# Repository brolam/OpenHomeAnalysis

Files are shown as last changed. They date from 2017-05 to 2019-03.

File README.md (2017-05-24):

# OHA - Open Home Analysis
<p>
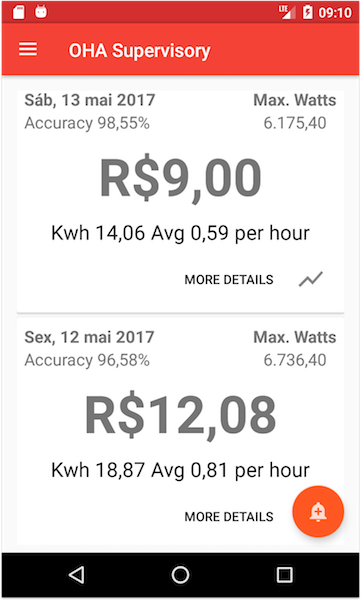
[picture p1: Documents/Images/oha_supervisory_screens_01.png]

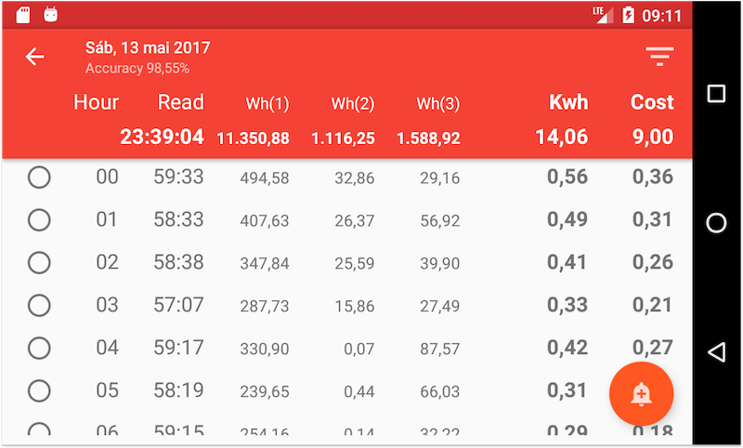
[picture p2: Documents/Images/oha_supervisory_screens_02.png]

</p>
OHA é uma solução desenvolvida sobre as plataformas Arduino e Android para analisar informações registradas por sensores instalados em uma residência. 

O primeiro sensor disponível registra a utilização de energia de todos os aparelhos conectados a rede elétrica da residência e todas as informações são analisadas através do aplicativo Supervisory para Android, que será responsável pelo armazenamento e disponibilização dessas informações.

É importante destacar que cada aparelho gera uma assinatura na utilização de energia na rede elétrica, dessa forma, é possível analisar a utilização de energia por aparelho e período através do aplicativo Supervisory.

Esse é um projeto Open Source / Open Hardware, sendo assim, todas as informações necessárias para desenvolve-lo estão disponíveis nesse repositório, além disso, também recomendo os vídeos abaixo disponíveis no youtube com mais detalhes do projeto: 

- [Visão Geral do Projeto](https://youtu.be/oC_cOZK9y08);
- [Desenvolvendo o Registrador de Utilização de Energia](https://youtu.be/WqODX3P4kZ0);

## Registrador de Utilização de Energia

### Protoboard
<p align="center">
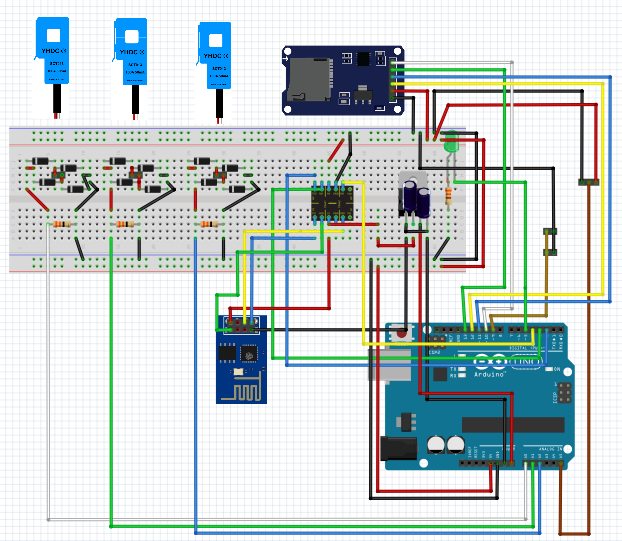
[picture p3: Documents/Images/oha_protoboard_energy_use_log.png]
  
</p> 

### PCB
<p align="center">
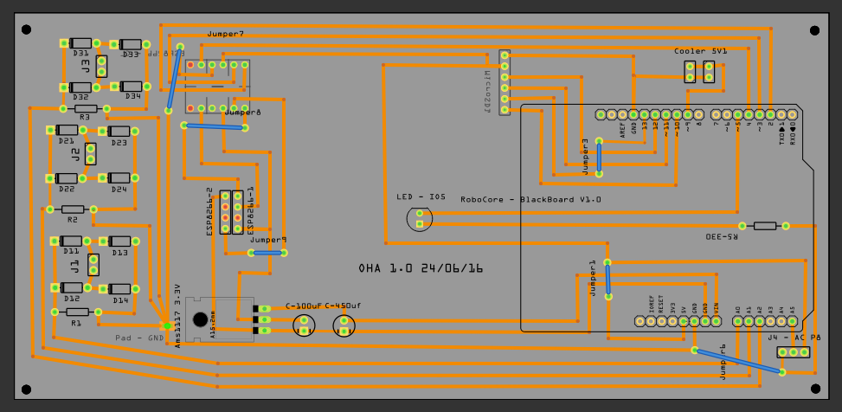
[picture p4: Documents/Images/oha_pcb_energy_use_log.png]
  
</p>
O objetivo da Protoboard na imagem acima é fornecer uma visão geral dos componentes e suas conexões, mas sugiro a construção da PCB, conforme orientações abaixo, para evitar problemas com as conexões que podem inviabilizar o funcionamento correto desse circuito. 

Segue abaixo a lista de componentes com o link das lojas onde eles foram adquiridos:
<table>
  <tr>
    <th width="30%">Componentes</th>
    <th>Descrição</th> 
    <th>Objetivo</th>
    <th>Preço</th>
  </tr>
  <tr></tr>
  <tr>
    <th></th>
    <th>Arduino UNO R3 ou compatível fabricado pela RoboCore.</th> 
    <th>Ler através das portas analógicas a utilização de energia e registrar no SD Card.</th>
    <th><a href="https://www.robocore.net/loja/produtos/arduino-blackboard.html">R$85,00</a></th>
  </tr>
  <tr></tr>
  <tr>
    <th></th>
    <th>MicroSD Card Adapter CATALEX v1.0.</th> 
    <th>Registrar temporariamente a utilização de energia.</th>
    <th><a href="http://www.usinainfo.com.br/modulos-para-arduino/sd-card-arduino-leitor-micro-sd-card-2637.html">R$12,90</a></th>
  </tr>
  <tr></tr>
  <tr>
    <th></th>
    <th>Módulo ESP8266-01</th> 
    <th>Disponibilizar os registros de utilização de energia através de uma conexão WiFI.</th>
    <th><a href="https://www.robocore.net/loja/produtos/modulo-wifi-esp8266.html">R$39,00</a></th>
  </tr>
  <tr></tr>
  <tr>
    <th></th>
    <th>Conversor de Nível Lógico RC 3,3V / 5V</th> 
    <th>Converter o nível lógico de 5V do Arduino para 3,3V na comunicação serial com o Módulo ESP8266-01.</th>
    <th><a href="https://www.robocore.net/loja/produtos/conversor-de-nivel-logico.html">R$8,50</a></th>
  </tr>
  <tr></tr>
  <tr>
    <th></th>
    <th>Regulador de Tensão Ams1117 3.3v P/ Esp8266</th> 
    <th>Transformar a alimentação do circuito de 9V para 3.3V e alimentar o Módulo ESP8266-01</th>
    <th><a href="http://produto.mercadolivre.com.br/MLB-711669968-modulo-regulador-tensao-ams1117-33v-p-esp8266-wifi-arduino-_JM">R$5,00</a></th>
  </tr>
  <tr></tr>
  <tr>
    <th></th>
    <th>3 X Sensores de Corrente Não Invasivo 100A SCT-013</th> 
    <th>Realizar a leitura da utilização de energia</th>
    <th><a href="http://www.filipeflop.com/pd-2025cd-sensor-de-corrente-nao-invasivo-100a-sct-013.html?ct=&p=1&s=1">R$47.90X3 = R$143,70</a></th>
  </tr>
  <tr></tr>
  <tr>
    <th></th>
    <th>Capacitor Eletrolítico 470uF / 16V</th> 
    <th>Estabilizar a alimentação entre a fonte de 9V e o regulador Tensão Ams1117 3.3v</th>
    <th><a href="http://www.baudaeletronica.com.br/capacitor-eletrolitico-470uf-16v.html">R$0,20</a></th>
  </tr>
  <tr></tr>
  <tr>
    <th></th>
    <th>Capacitor Eletrolítico 10uF / 16V</th> 
    <th>Estabilizar a alimentação entre o regulador de Tensão Ams1117 3.3v e o Módulo ESP8266-01</th>
    <th><a href="http://www.baudaeletronica.com.br/capacitor-eletrolitico-10uf-16v.html?gclid=CJGrgOLo7NMCFUlMDQodi3kNyw">R$0,20</a></th>
  </tr>
  <tr></tr>
  <tr>
    <th></th>
    <th>3 X Resistores (33Ω)</th> 
    <th>Dividir a tensão do SCT-013 para os 5V nas portas analógicas do Arduino</th>
    <th><a href="http://www.baudaeletronica.com.br/resistor-33r-5-1-4w.html">R$0.10X3 = R$0,30</a></th>
  </tr>
  <tr></tr>
  <tr>
    <th></th>
    <th>12 X Diodos In4007 ou equivalentes</th> 
    <th>Transformar a corrente alternada do SCT-013 em corrente contínua através de uma ponte retificadora.</th>
    <th>R$0.20X12 = R$2,40</th>
  </tr>
  <tr></tr>
  <tr>
    <th></th>
    <th>3 X Conectores 5045 2 Pinos Macho</th> 
    <th>Conectar os SCT-013 ao circuito.</th>
    <th><a href="http://www.usinainfo.com.br/conectores-e-soquetes/conector-5045-2-pinos-macho-kit-com-5-unidades-3485.html">R$0,32X3 = R$0,96</a></th>
  </tr>
  <tr></tr>
  <tr>
    <th></th>
    <th>3 X Conectores 5051 2 Pinos Fêmea</th> 
    <th>Conectar os SCT-013 ao circuito.</th>
    <th><a href="http://www.usinainfo.com.br/conectores-e-soquetes/conector-5045-2-pinos-macho-kit-com-5-unidades-3485.html">R$0,38X3 = R$1,14</a></th>
  </tr>
  <tr></tr>
  <tr>
    <th></th>
    <th>2 X Barras de 10 pinos fêmea / Conector Empilhável</th> 
    <th>Conectar o MicroSD Card e Regulador Tensão Ams1117 ao circuito.</th>
    <th><a href="http://www.usinainfo.com.br/barras-de-pinos/barra-de-10-pinos-femea-conector-empilhavel-2530.html">R$2,00X2 = R$4,00</a></th>
  </tr>
  <tr></tr>
  <tr>
    <th></th>
    <th>Barra de 40 pinos fêmea / Conector Empilhável para PCI</th> 
    <th>Conectar o Módulo ESP8266-01 e Conversor de Nível Lógico RC 3,3V ao circuito.</th>
    <th>
        <a href="http://www.usinainfo.com.br/barras-de-pinos/barra-de-40-pinos-femea-conector-empilhavel-para-pci-3109.html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">R$3,85</a>
    </th>
  </tr>
  <tr></tr>
  <tr>
    <th></th>
    <th>Barra de pinos macho 1x40 vias com passo de 2,54mm 180°</th> 
    <th>Conectar o Arduino UNO R3 ou compatível ao circuito.</th>
    <th>
        <a href="http://www.usinainfo.com.br/barras-de-pinos/barra-de-pinos-macho-1x40-vias-com-passo-de-254mm-180-preto-2748.html">R$1,90</a>
    </th>
  </tr>
  <tr></tr>
  <tr>
    <th></th>
    <th>Placa de Fenolite Cobreada Simples 10x20 cm</th> 
    <th></th>
    <th>
         <a href="http://www.usinainfo.com.br/circuito-impresso/placa-de-fenolite-cobreada-simples-10x20-cm-para-circuito-impresso-3841.html">R$6,90</a>
    </th>
  </tr>
  <tr></tr>
  <tr>
    <th></th>
    <th>LED 5mm Difuso e um Resistor de (330Ω) </th> 
    <th>Informar se a utilização de energia foi registrada com sucesso.</th>
    <th>
         <a href="http://www.usinainfo.com.br/leds/led-amarelo-5mm-difuso-kit-com-5-unidades-2978.html">R$0,40 + R$0,30 = R$0,70</a>
    </th>
  </tr>
  <tr></tr>
  <tr>
    <th></th>
    <th>Fonte de Alimentação para Arduino 9VDC 1A</th> 
    <th>Alimentar todo o circuito.</th>
    <th><a href="http://www.usinainfo.com.br/fonte-de-alimentacao/fonte-de-alimentacao-para-arduino-9vdc-1a-2424.html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">R$18,85</a>
    </th>
  </tr>
  <tr></tr>
  <tr>
    <th></th>
    <th>Cartão De Memória Microsd 2gb</th> 
    <th>Armazenar temporariamente os registros de utilização de energia.</th>
    <th>R$15,85</th>
  </tr>
</table>
O custo estimado considerando somente os componentes é de aproximadamente R$351,35, sendo importante destacar que será necessário dedicar um smartphone ou tablet Android para monitorar o Registrador de Energia.

## Construindo e Instalando o Registrador de Utilização de Energia
### PCB

<p align="center">
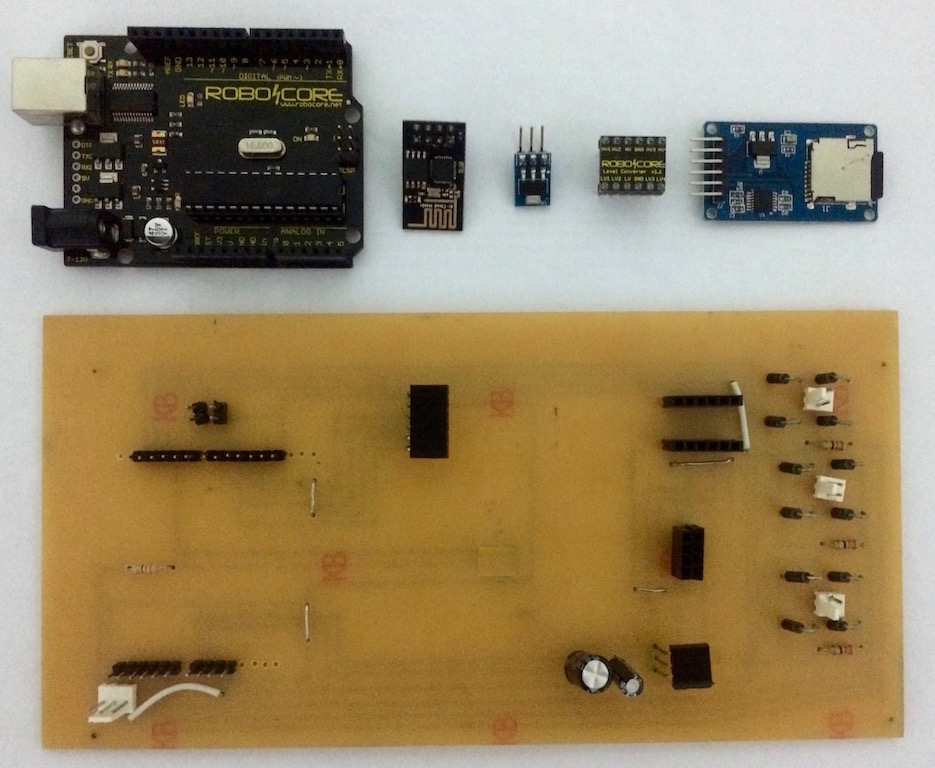
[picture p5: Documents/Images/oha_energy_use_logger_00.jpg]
  
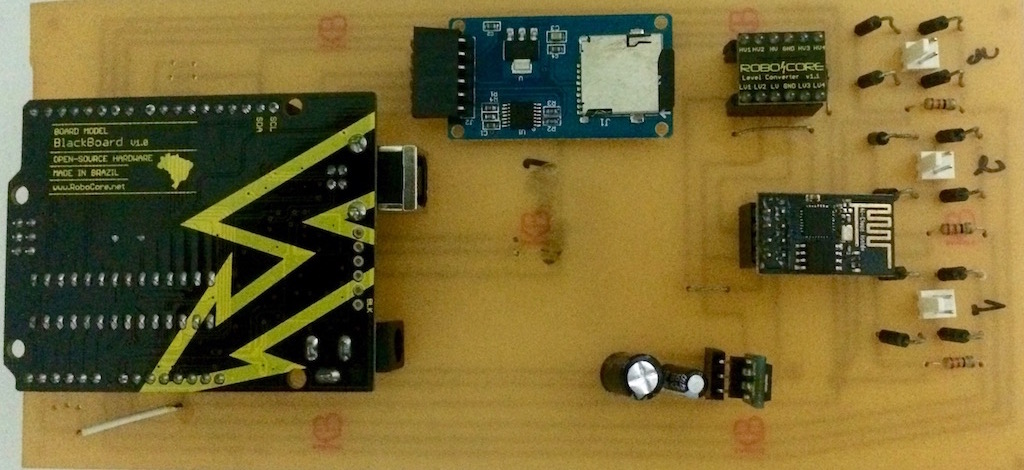
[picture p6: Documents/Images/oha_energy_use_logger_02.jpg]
  
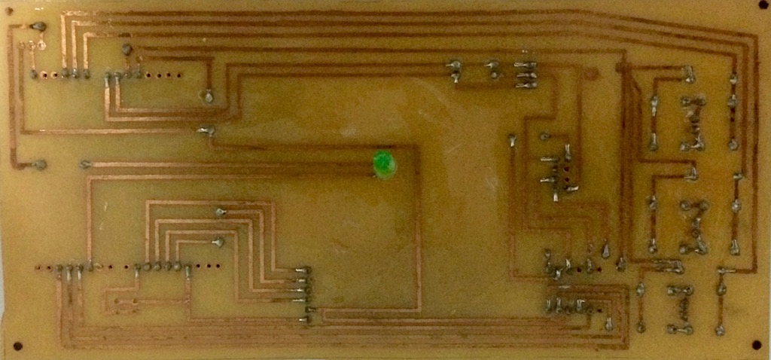
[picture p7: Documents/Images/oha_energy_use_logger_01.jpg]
  
</p>
A placa pode ser construída utilizando a técnica de termotransferência do circuito impresso via impressora laser, sendo assim, o <a href="https://raw.githubusercontent.com/brolam/OpenHomeAnalysis/master/Documents/Images/oha_pcb_energy_use_logger.pdf">PDF</a> do circuito também está disponível nesse repositório para facilitar a impressão. <br>Também clique na imagem acima para ampliá-la é visualizar com mais detalhes como cada componente deve ser instalado na placa.

### Instalação 
<table>
  <tr>
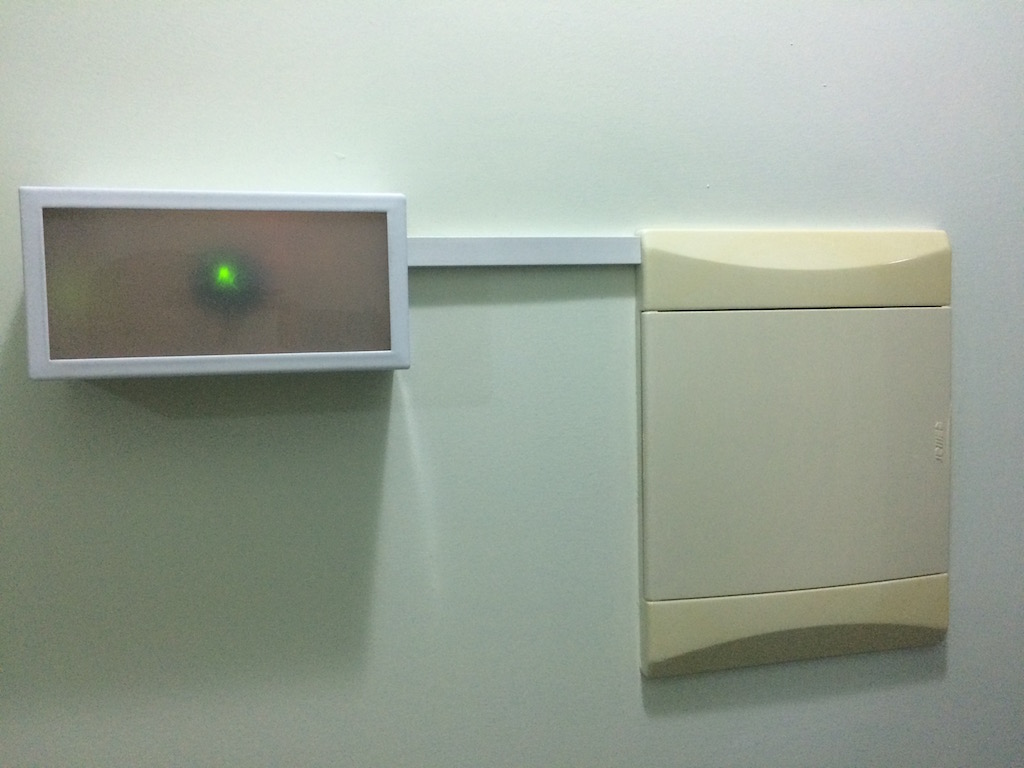
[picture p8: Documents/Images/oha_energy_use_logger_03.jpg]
    <th th width="40%"></th>
    <th>A placa junto com a fonte de 9V podem ser instaladas em uma ARANDELA medindo 20cmX10cm e 7,5cm de profundidade ao lado do quadro de distribuição elétrica;</th>
  </tr>
  <tr></tr>
  <tr>
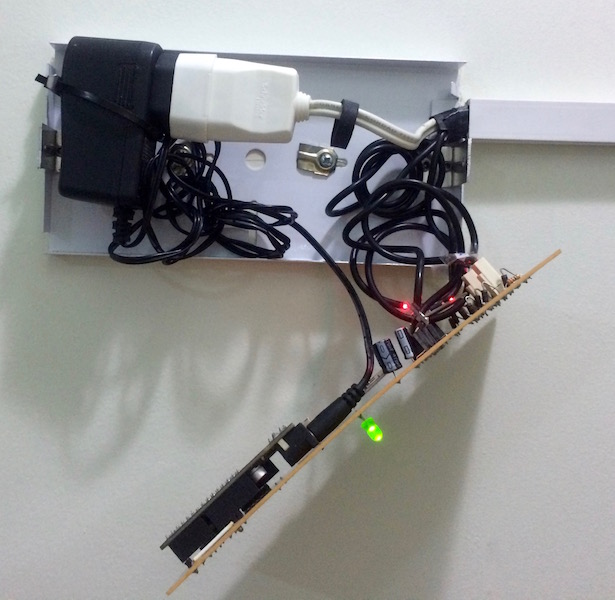
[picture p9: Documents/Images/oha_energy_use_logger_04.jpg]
    <th></th>
    <th>Veja na imagem ao lado a instalação da placa junto com a fonte de 9V;</th> 
  </tr>
  <tr></tr>
  <tr>
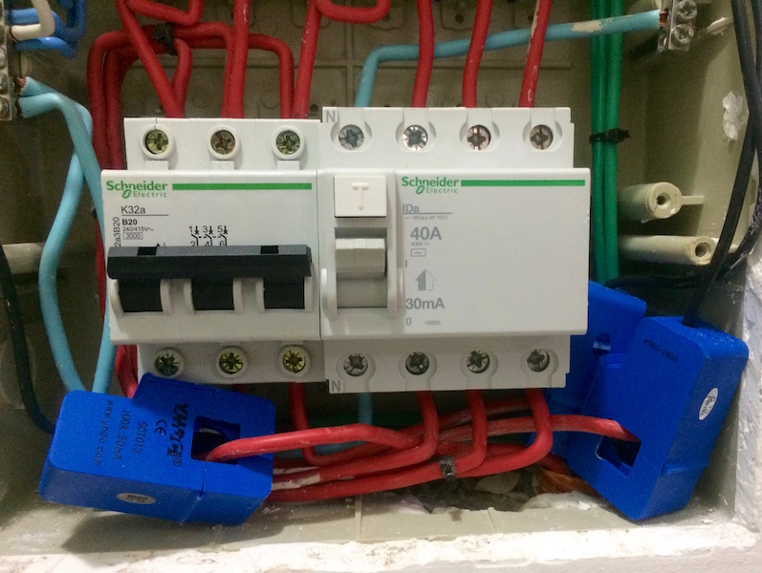
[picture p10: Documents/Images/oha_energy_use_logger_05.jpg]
    <th></th>
    <th>Também observe a instalação dos sensores SCT-013 em cada fase.</th> 
  </tr>
</table>

## Carregando o Firmware no Módulo ESP8266 e Arduino 

### ESP8266
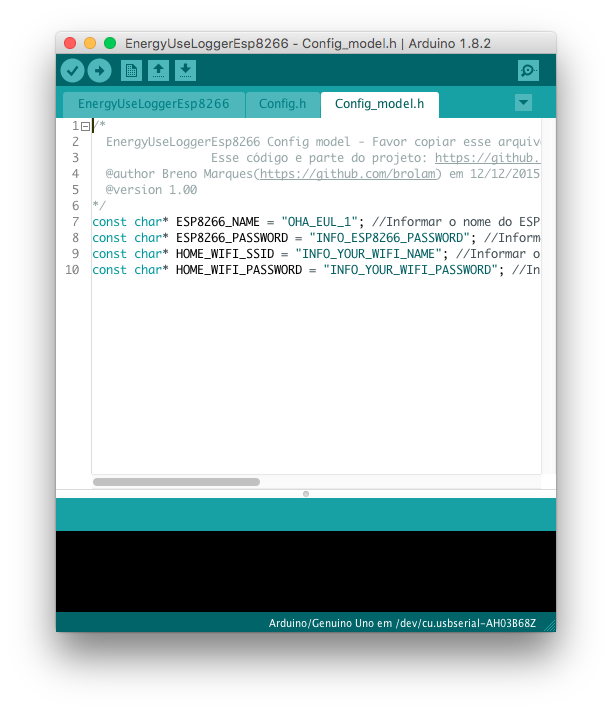
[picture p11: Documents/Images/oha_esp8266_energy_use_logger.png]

Antes de carregar o firmware disponível em <a href="https://github.com/brolam/OpenHomeAnalysis/tree/master/Firmware/EnergyUseLoggerEsp8266">Firmware/EnergyUseLoggerEsp8266</a> no módulo ESP8266, é necessário copiar o arquivo Config_model.h para o Config.h no mesmo diretório e configurar os parâmetros exibidos na imagem acima. Caso exista alguma dificuldade para conectar o módulo ESP8266 via USP e realizar a carga, sugiro a leitura do tutorial disponível em <a href="https://www.robocore.net/loja/produtos/modulo-wifi-esp8266.html">www.robocore.net</a>.

### Arduino
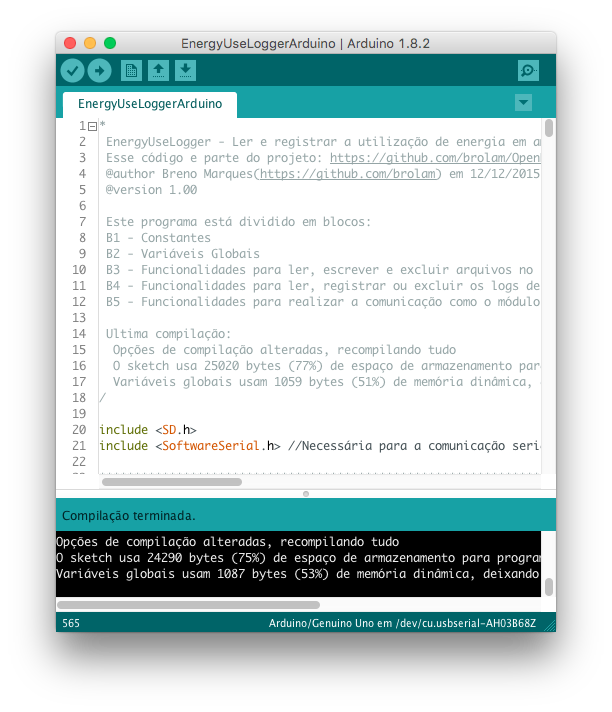
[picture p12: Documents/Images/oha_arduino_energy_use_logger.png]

O firmware para o Arduino está disponível em <a href="https://github.com/brolam/OpenHomeAnalysis/tree/master/Firmware/EnergyUseLoggerArduino">Firmware/EnergyUseLoggerArduino</a>. </br>Observação: se o Arduino estiver conectado a placa, também será necessário conectá-lo a fonte de 9V, porque somente a alimentação via USB não será suficiente para alimentar todo o circuito.

### Fritzing
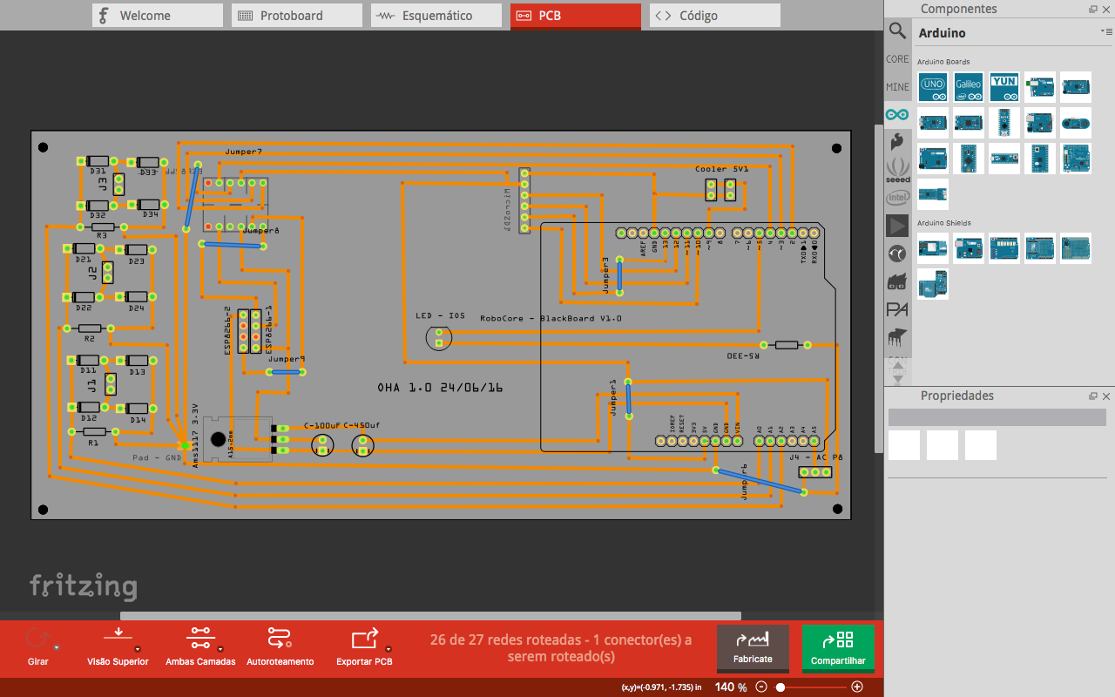
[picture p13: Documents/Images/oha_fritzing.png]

Caso seja necessário realizar alguma modificação no circuito, o arquivo .fzz também está disponível nesse repositório <a href="https://github.com/brolam/OpenHomeAnalysis/tree/master/Documents/Fritzing/OhaEnergyUseLog.fzz">Documents/Fritzing/</a>.

## Instalando e Configurando o Aplicativo Supervisory

### Instalação através do Google Play
O aplicativo Supervisory está disponível na loja de aplicativos, favor procurar por <a href="https://play.google.com/store/apps/details?id=br.com.brolam.oha.supervisory">OHA - Open Home Analysis</a> e realizar a instalação.

### Instalação através do Android Studio
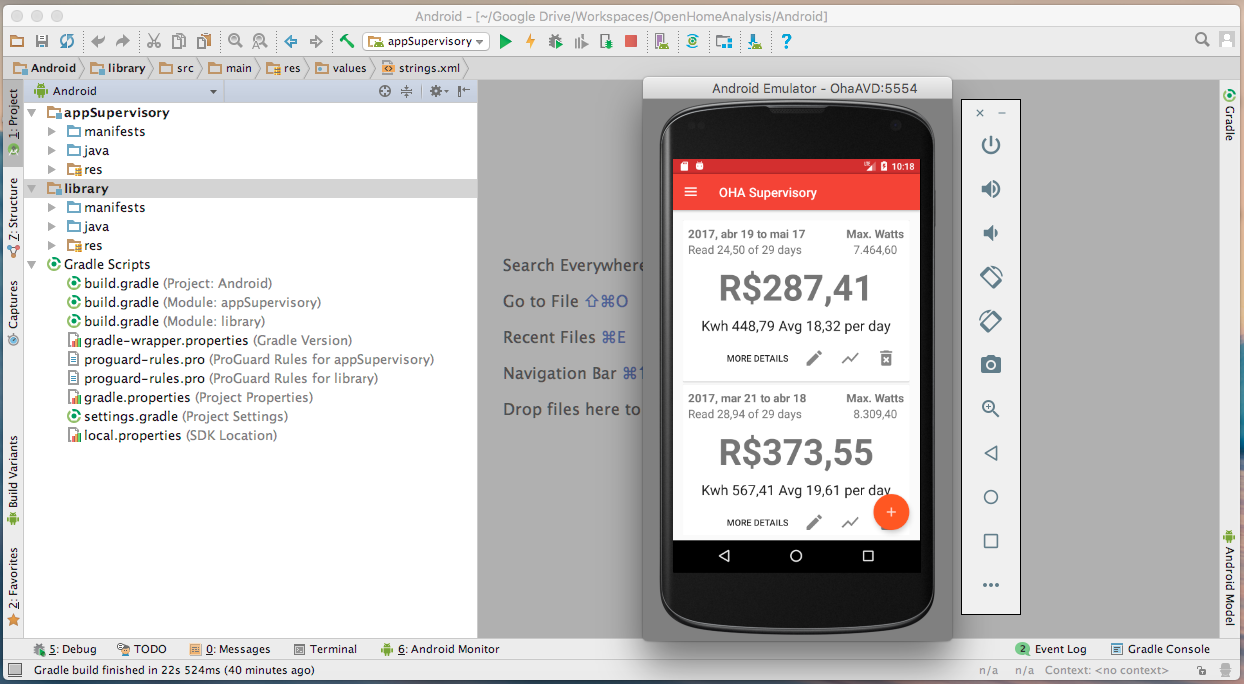
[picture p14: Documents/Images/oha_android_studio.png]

O código fonte do aplicativo Supervisory também está disponível nesse repositório em <a href="https://github.com/brolam/OpenHomeAnalysis/tree/master/Android">Android/</a>. Sendo assim, é possível realizar a instalação e modificações através do Android Studio.

### Configurando o Registrador de Utilização de Energia no aplicativo Supervisory
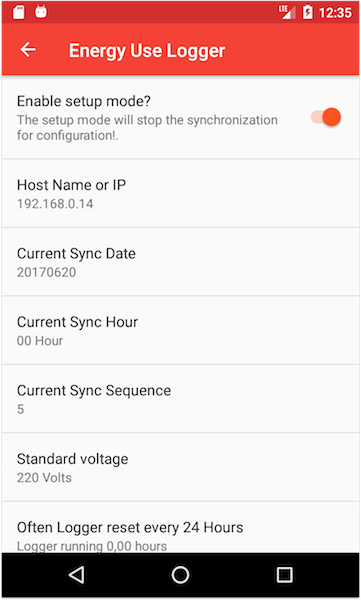
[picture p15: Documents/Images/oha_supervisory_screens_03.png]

No aplicativo /Settings/Energy Use Logger, conforme imagem acima, é possível preencher os parâmetros para conectar o aplicativo ao Registrador de Utilização de Energia.

## Próximas Funcionalidades
Novas funcionalidades, melhorias e correções serão cadastradas na <a href="https://github.com/brolam/OpenHomeAnalysis/issues">Lista de Questões(Issues)</a> desse repositório, então, basta seguir esse repositório para receber notificacões sobre as novidades.

## Contribuições
Fique a vontade para contribuir e acompanhe a <a href="https://github.com/brolam/OpenHomeAnalysis/issues">Lista de Questões(Issues)</a> do projeto ou entre em contato através do e-mail breno@brolam.com.br

## Links importantes para o desenvolvimento do projeto

- <a href="https://www.embarcados.com.br/">Embarcados</a> 
- <a href="https://openenergymonitor.org/">Open Energy Monitor</a> 
- <a href="https://www.youtube.com/channel/UCpOlOeQjj7EsVnDh3zuCgsA">Eletrônica Já!</a> 
- <a href="https://www.youtube.com/channel/UClT57Bq5io_kABtihe67C7w">All Electronics</a> 
- <a href="http://www.usinainfo.com.br/">Usinainfo</a> 
- <a href="https://www.robocore.net/">Robocore</a> 
- <a href="https://www.youtube.com/channel/UCpOlOeQjj7EsVnDh3zuCgsA">Adafruit Industries</a> 
- <a href="https://www.youtube.com/channel/UCVHFbqXqoYvEWM1Ddxl0QDgw">Android Developers</a>

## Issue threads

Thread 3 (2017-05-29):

App Supervisory - Tela de detalhes da conta de energia.

brolam, 2017-05-29:
Desenvolver a tela de detalhes da conta de energia:
1 - Exibir a utilização de energia por dia no período da conta de energia;
2 - Permitir a realização de filtros por faixa de hora, minuto e segundo e também por faixa de watts por fase.

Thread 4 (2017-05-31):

GO V1.0 - Processo de autenticação do Usuário.

brolam, 2017-05-31:
- Criar projeto no Firebase e configurar o authentication providers.
- Criar processo de autenticação no aplicativo Supervisory.
- Criar processo de autenticação no aplicativo OHA GO iOS.

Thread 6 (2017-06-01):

Energy Use Logger V2.0 - S1

brolam, 2017-06-01:
Desenvolver o registrador de utilização de energia através da seguinte solução:
S1 - NodeMcu Lua CH340G ESP8266 com Leonardo Pro Micro ATmega32U4

brolam, 2017-06-17:
Realizado teste de gravação e leitura no Micro SD Card: Não foi possível realizar a conexão alimentando o módulo com 3.3V, mas a gravação e leitura foi realizada com sucesso e com uma ótima performance alimentando o módulo Micro SD Card com 5V.

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

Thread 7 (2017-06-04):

EnergyUseLogger - Arduino Travamento

brolam, 2017-06-04:
Depois de horas ou dias somente o Arduino trava interrompendo o registro de utilização de energia, mas o módulo ESP8266 continua respondendo as requisições http.

brolam, 2017-06-04:
Foi identificado que o travamento acontece na leitura ou escrita no MicroSD, e somente após uma formatação completa do MicroSD o problema foi corrigido. Novos testes serão realizados para confirmar a correção do problema.

Closed 2017-06-09.

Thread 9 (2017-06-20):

Melhorar o caso de teste OhaEnergyUseApiV1Test.

brolam, 2017-06-20:
Melhorar o caso de teste com o objetivo de testar o comportamento da OhaEnergyUseApiV1 independente do modelo do OhaEnergyUseLogger que ela está conectada.

Assim será possível verificar que todos os modelos do OhaEnergyUseLogger ( Arduino ou NodeMcu ) estão realizando o mesmo comportamento no registro e leitura da utilização de energia.

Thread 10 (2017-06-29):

EnergyUseLogger - Lentidão na gravação dos registros de utilização de energia.

brolam, 2017-06-29:
Depois de armazenar mais de cincos dias no Micro-SD de 8G, está ocorrendo uma lentidão na gravação nos logos de utilização de energia.

Esse problema também está diminuindo a precisão no tempo total de leitura da utilização de energia.

Closed 2017-07-01.

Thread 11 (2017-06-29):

EnergyUseLogger - Erro na exclusão dos registros temporários de utilização de energia.

brolam, 2017-06-29:
Para liberar espaço no Micro-SD, o registrador de utilização de energia deve excluir os registros que já foram exportado para o aplicativo Supervisory. Mas esse processo está travando o registrador no momento da exclusão do registro de utilização de energia.

brolam, 2017-07-17:
Esse problema será corrigido na nova versão do registrador: issue #6

Closed 2017-07-17.

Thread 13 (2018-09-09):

Gravar registros de energia

brolam, 2018-09-09:
Refazer a funcionalidade de gravação e importação dos registros de energia para melhoria a performance, diminuir o tamanho do programa e corrigir a exclusão dos registros já importados.

brolam, 2018-11-02:
Concluído. Aplicativo também atualizado e disponível em https://play.google.com/store/apps/details?id=br.com.brolam.oha.supervisory

Closed 2018-11-02.

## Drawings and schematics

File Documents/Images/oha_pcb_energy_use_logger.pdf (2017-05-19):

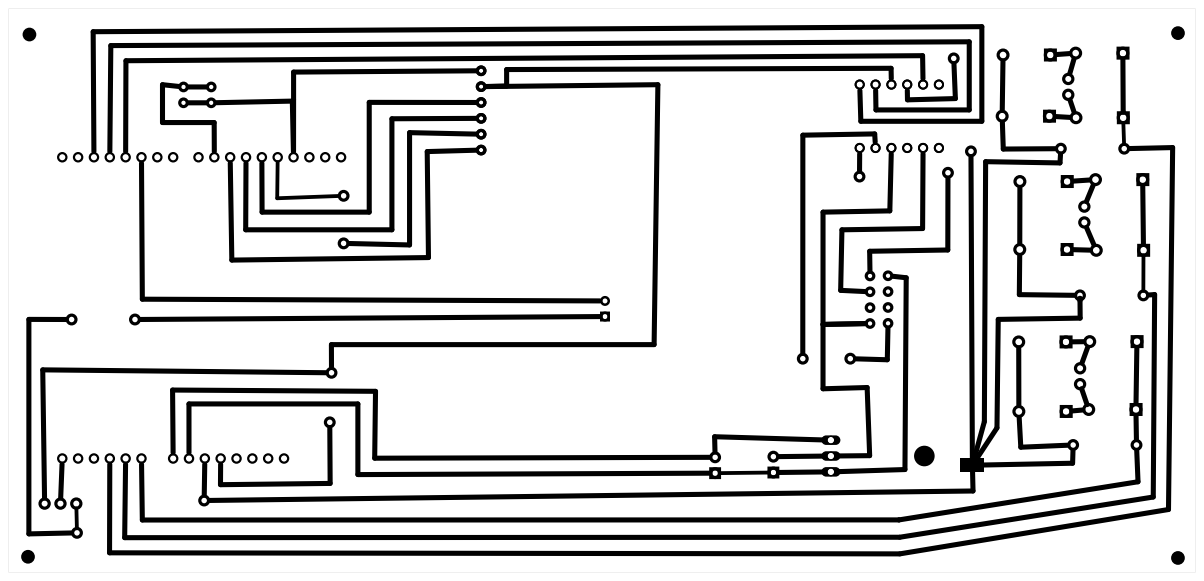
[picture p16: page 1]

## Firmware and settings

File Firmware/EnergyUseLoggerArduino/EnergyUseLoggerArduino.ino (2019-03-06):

/*
  EnergyUseLogger - Ler e registrar a utilização de energia lendo os sensores SCT - 013 conectados ao circuito.
  Esse código e parte do projeto: https://github.com/brolam/OpenHomeAnalysis
  @author Breno Marques(https://github.com/brolam) em 12/12/2015.
  @version 1.2.0
*/

#include <SD.h>
#include <SoftwareSerial.h> //Necessária para a comunicação serial com o modulo WiFi ESP8266.
//#define DEBUG 1 //Escrever no Monitor serial quando ativado, {@see debug()},
#define LED_LOG_SAVE 5                  //Informar a porta do LED, para sinalizar a gravação do log da utilização de energia. 

//Constantes utilizadas na geração dos logs.
#define AMOUNT_SCT 3                    //Quantidade de sensores SCT-013 suportado no circuito.  
#define INTERVAL_TIME_SAVE_LOG 10000    //Intervalo em Milissegundo para registrar o proximo log, {@see saveLog()}    

//Constantes utilizadas na gravação dos arquivos.
#define SD_CS 10                        //The pin connected to the chip select line of the SD card, @link https://www.arduino.cc/en/Reference/SDbegin
#define F_BEGIN F("<")                  //Sinalizar o inicio do conteúdo de registro de utilização de entergia 
#define F_END F(">")                    //Sinalizar o final do conteúdo de registro de utilização de entergia
#define LINE_END '\n'                   //Sinalizar o final da linha do registro de utilização de entergia
#define F_TXT F(".txt")                 //Extensão dos arquivos de logs de registros de energia

//Constantes utilizadas na comunicação com o modulo WiFi ESP8266
#define URL_LOG F("log")                                 //Solicitação de logs
#define URL_STATUS F("status")                           //Solicitação(GET) ou alteração(POST) do Status do programa, para mais detalhes {@see setStatus()} e {@see sendStatus()} 
#define URL_RESET F("reset")                             //Solicitação para reiniciar o Arduino, para mais detalhes {@see reset()}
#define LOG_DATE_NOT_EXISTS F("LOG_DATE_NOT_EXISTS")     //Sinalizar que o log não existe na data e hora solicitada.
#define LOG_END_OF_FILE F("LOG_END_OF_FILE")             //Sinalizar que a leitura dos logs chegou ao final.
#define LOG_DELETED F("LOG_DELETED")                     //Sinalizar que o log foi excluido.
#define OHA_STATUS_FINISHED F("OHA_STATUS_FINISHED")     // Sinalizar que a geração de logs está finalizada para a data e hora solicitada
#define OHA_STATUS_RUNNING F("OHA_STATUS_RUNNING")       // Sinalizar que a geração de logs esta ativa  para a data e hora solicitada

//Constantes para definir o status de execução do programa.
#define OHA_STATUS_NOT_DATE F("OHA_STATUS_NOT_DATE")    //Sinalizar que a data do programa não está atualizada. 
#define OHA_STATUS_NOT_SD F("OHA_STATUS_NOT_SD")        //Sinalizar que o SD Card está com problema e os registros dos logs está parado.   
#define OHA_STATUS_OK F("OHA_STATUS_OK")                //Sinalizar que a data do programa está atualizada / registrando os logs de utilização de energia. 

String ohaStatus = String("");                         //Armazenar o status atual do programa.
String currentDate = String("");                       //Armazenar a data atual para o registro dos logs no formato YYYYMMDD
String currentTime = String("");                       //Armazenar a hora + minutos atual para o registro dos logs no forma HHmm
unsigned long millisOnSetTime = 0;                     //Armazenar o total de Milissegundo {@see millis()}, quando a data e hora do programa foi atualizada, para mais detalhes veja {@see setDate()}
unsigned long intervalSaveLog = 0;                     //Armazenar o tempo que o ultimo log foi salvo, por favor, veja {@see saveLog()} para mais detalhes.
byte espCheck = 0;                                     //Armazenar o total de verificação do status do modulo ESP8266 {@see esp8266Reset()}.

SoftwareSerial esp8266(2, 3); //Comunicação serial com o modulo ESP8266.

#ifdef DEBUG
void debug(String title, String value) {
  Serial.print(title); Serial.println(value);
}
#endif

#ifdef DEBUG
void debug(String title) {
  Serial.println(title);
}
#endif

/* Abrir um arquivo no cartão de memória conforme parametros abaixo:
   IMPORTANTE: O arquivo deve ser fechado, {@see file.close()}, no final do processo!
*/
File getFile(String fileName, boolean readOnly) {
  return SD.open(fileName, ( readOnly ? FILE_READ : FILE_WRITE));
}

String getLogFileName(String date, String strTime) {
  return date.substring(0, 6) + strTime.substring(0, 2) + String(F_TXT);
}

String getStatusByDateHour(String strDate, String strHour) {
  return ((strDate == currentDate) && (currentTime.substring(0, 2) == strHour.substring(0, 2)) ? String(OHA_STATUS_RUNNING) : String(OHA_STATUS_FINISHED));
}

/* Preencher uma lista com a média da leituras dos sensores SCT 13 */
void fillReads(double reads[AMOUNT_SCT])
{
  int counts[AMOUNT_SCT];
  double readSum[AMOUNT_SCT];
  //Inicializa os valores das listas com zero:
  for (byte z = 0; z < AMOUNT_SCT; z++) {
    counts[z] = 0;
    readSum[z] = 0.00;
  }
  //Realizar 2000 leituras nas portas analogicas. Essa quantidade de leitura gera um valor mais próximos dos valores
  //medidos com o amperímetro. Somente ler valores maior do que zero.
  for (int i = 0; i < 2000; i++)
  {
    for (int r = 0; r < AMOUNT_SCT; r++)
    {
      int _analogRead = analogRead(r);
      if (_analogRead > 0 )
      {
        readSum[r] += _analogRead;
        counts[r] ++;
      }
    }
  }

  //Aplicar a média das leitura nos sensores:
  for (byte a = 0; a < AMOUNT_SCT; a++)
  {
    reads[a] =  (( counts[a]  > 10 ) ?  (readSum[a] / counts[a]) : 0.00) ;
#ifdef DEBUG
    debug("A" + String(a) + ": " , String((counts[a] > 0 ? ( readSum[a] / counts[a] ) : 0.00)) );
    debug("C" + String(a) + ": " , String(counts[a]) );
#endif
  }
}

/* Registrar um log de utilização de energía no cartão de memória.*/
void saveLog() {
  double reads[AMOUNT_SCT];
  fillReads(reads);

  //Verifica se o tempo de intervalo para gravar o próximo log foi alcançado:
  while ( (millis() - intervalSaveLog) < INTERVAL_TIME_SAVE_LOG ) {
    delay(100);
  }
  //Reiniciar o intervalo do tempo que o log deve ser gavado nesse ponto, para não contabilizar o tempo
  //da gravação do próximo logo.
  intervalSaveLog = millis();
#ifdef DEBUG
  debug(F("Sensors Reads: "), (String(reads[0]) + String(" / ") + String(reads[1]) + String(" / ") + String(reads[2])));
#endif
  String fileName = getLogFileName(currentDate, currentTime); // Nome do arquivo do log.
  File fileLog = getFile(fileName, false);
  fileLog.print(F_BEGIN); // Inicio do conteúdo do log
  fileLog.print(currentTime.substring(0, 6)); fileLog.print('|'); //Ultima hora e minuto atualizada no programa.
  fileLog.print(getVolts()); fileLog.print('|');
  //Gerar um coluna para cada leitura dos SCT 013 disponíveis no circuito:
  for (byte s = 0; s < AMOUNT_SCT; s++)
  {
    fileLog.print((reads[s] > 0 ? reads[s] : 0.00)); fileLog.print('|');
  }
  fileLog.print(millis() - millisOnSetTime); //Total de Milissegundo desde a ultima atualização da data e hora no programa, para mais detalhes, veja B4/Observação 02.
  fileLog.print(F_END); //Final do conteudo do log, somente logs com essa sinalização serão considerados válidos.
  fileLog.print(LINE_END); //Sinaliza o final do log ou final da linha no arquivo de log.
  fileLog.close();
#ifdef DEBUG
  debug(F("path:"), fileName);
#endif
}

/* Enviar uma lista de logs para o módulo ESP8266 via comunicação serial conforme parametros abaixo:
   @param strDate informar texto com data no formato YYMMDD
   @param strHour informar texto com hora e minuto no formato HHmm
   @param start informar o inicio da sequência do log.
   @param amount informar a quantidade de logs.
*/
void sendLog(String strDate, String strHour, int startPosition, int amount ) {
  int countReadLogs = 0;
  String pathLog = getLogFileName(strDate, strHour);
  if ( !SD.exists(pathLog) ) {
    esp8266.println(LOG_DATE_NOT_EXISTS);
    return;
  }
  File logFile = getFile(pathLog, true);
  if ( !logFile.seek(startPosition)  )
  {
    esp8266.println(String(LOG_END_OF_FILE));
#ifdef DEBUG
    debug(F("SendLog not seek: "), String(startPosition));
#endif
    return;
  }
  do {
    String nextLogContent = logFile.readStringUntil(LINE_END);
    if ( nextLogContent.length() > 0  ) {
      esp8266.println(String(logFile.position()) + ':' + nextLogContent);
#ifdef DEBUG
      debug(F("SendLog: "), String(logFile.position()) + ':' + nextLogContent);
#endif
    } else {
      esp8266.println(String(LOG_END_OF_FILE));
#ifdef DEBUG
      debug(F("SendLog: "), String(LOG_END_OF_FILE));
#endif
      break;
    }
    //Necessário para sincronizar a comunicação serial e evitar dados truncados.
    delay(300);
    countReadLogs++;
  } while (countReadLogs <= amount);
  esp8266.println( getStatusByDateHour(strDate, strHour));
#ifdef DEBUG
  debug(F("SendLog: "), getStatusByDateHour(strDate, strHour));
#endif
  logFile.close();
}

/* Atualizar o status do programa e também a data e hora utilizada no registro do log de utilização de energía:
   @param strDate informar texto com data no formato YYMMDD
   @param strDate informar texto com hora e minuto no formato HHmm
*/
void setStatus(String strDate, String strTime) {
  currentDate = strDate;
  currentTime = strTime;
  millisOnSetTime = millis(); //Reiniciar a contagem de milissegundos para a nova data e hora, para mais informações vaje B3/Obeservação 02.
  ohaStatus = OHA_STATUS_OK; //Sinalizar que a gravação dos logs estão sendo realizadas sem problemas.
  delay(100);
}

/* Evniar para o módulo ES8266 vai comunicação serial as informações do status do programa.
   @param strDate informar texto com data no formato YYMMDD
   @param strHour informar texto com hora e minuto no formato HHmm
*/
void sendStatus(String strDate, String strTime) {
  String path = getLogFileName( strDate, strTime);
  if ( !SD.exists(path) )
  {
    esp8266.println(LOG_DATE_NOT_EXISTS);
  } else {
    /*Status da sequencia:
         RUNNING - Novas logs estão sendo geradas para a data e hora informada;
         STOPPED - Geração de logs finalizada para a data e hora informada.
    */
    esp8266.print(F_BEGIN); // Inicio do conteúdo do log
    esp8266.print(getStatusByDateHour(strDate, strTime));
    esp8266.print("|");
    esp8266.print(millis()); // Informar o tempo que o dispositivo está funcionando desde a ultima inicialização.
    esp8266.println(F_END);
  }
  esp8266.flush();
}

/*
  Excluir logs de utilização de energía para liberar espaço no cartão de memória.
*/
void deleteLogs(String strDate, String strHour)
{
  String deleteLog = getLogFileName(strDate, strHour);
  if ( SD.exists(deleteLog)) {
#ifdef DEBUG
    debug(F("Try delete: "), deleteLog);
#endif
    SD.remove(deleteLog);
    esp8266.println(LOG_DELETED);
#ifdef DEBUG
    debug(F("Deleted: "), deleteLog);
#endif
  } else {
    esp8266.println(LOG_DATE_NOT_EXISTS);
#ifdef DEBUG
    debug(F("Delete Log - Not Exists"), deleteLog);
#endif
  }
}

/* Reservada para realizar a leitura da tensão, se o valor for zero, considerar o valor padrão
  da tensão, exemplo: 220 ou 110*/
double getVolts() {
  return 0.00;
}

/* Final do B4*/

/***************************************************************************************************************************************************************
   Inicio do B5 - Funcionalidades para realizar a comunicação como o módulo WiFi.
   Visão geral: Nesse bloco de códigos estão as funcionalidades para a comunicação com o módulo ESP8266 via serial.
 ***************************************************************************************************************************************************************/

/* Transformar uma URL em uma lista de parâmetros.
   @param url informar uma URL válida.
   @param params informar uma lista de textos com 10 itens.
*/
void parseUrl(String url, String params[]) {
#ifdef DEBUG
  debug(F("URL: "), url);
#endif
  //Dividir a url por "/" e atribuir para cada item do params[].
  for (byte iParam = 0; iParam < 10; iParam++ ) {
    int index = url.indexOf("/");
    if ( index != -1 ) {
      params[iParam] = url.substring(0, index);
      url.remove(0, index + 1);
    }
  }
}

/* Executar a funcionalidade informada na Url enviada via o módulo ESP8266.
   ATENÇÃO: A quantidade de parâmetros, incluindo o tipo do Web Method POST ou GET, é
   limitado a 10 itens!
   @param url informar uma URL válida.
*/
void doUrl(String url) {
  String params[10];
  parseUrl(url, params); //Transformar a Url em uma lista de parâmtros, sendo o item 0 o tipo do Web Method, GET ou POST.
  boolean isGet = ( params[0].indexOf("GET") != -1);
  boolean isPost = ( params[0].indexOf("POST") != -1);
  boolean isDelete = ( params[0].indexOf("DELETE") != -1);
  //Se o cartão de memória não estiver disponível a funcionalidade nas URL abaixo não será executada.
  if ( ohaStatus != OHA_STATUS_NOT_SD) {
    //Atualizar a data do programa.
    //Reiniciar o programa 
    if (isPost && ( params[1] == URL_RESET ) ) {
      software_Reset();    
    } else if (isPost && ( params[1] == URL_STATUS ) ) {
      setStatus(params[2], params[3]);
    }
    //Somente executar as funcionalidade abaixo se o Status do programa for igual a OHA_STATUS_OK
    else if ( ohaStatus == OHA_STATUS_OK ) {
      //Enviar logs de utilização de energia:
      if ( isGet && ( params[1] == URL_LOG ) ) { //Enviar logs
        sendLog(params[2], params[3], params[4].toInt(), params[5].toInt());
      } else if ( isDelete && ( params[1] == URL_LOG ) ) { //Excluir Logs
        deleteLogs(params[2], params[3]);
      } else if (isGet && params[1] == URL_STATUS) { //Enviar status do programa.
        sendStatus(params[2], params[3]);
      } else {
#ifdef DEBUG
        debug(F("Url invalid :"), params[1] );
#endif
      }
    }
  }
  //Enviar somente o status do programa se houver algum problema.
  if ( ohaStatus != OHA_STATUS_OK) {
    esp8266.println(ohaStatus);
  }
  esp8266.println("OHA_REQUEST_END"); //Sinalizar o final da comunicação com o módulo ESP8266.
  delay(300);
}

/*Reiniciar o módulo ESP8266*/
void esp8266Reset() {
  const byte PIN_ESP8255_RST = 4;
  pinMode(PIN_ESP8255_RST, OUTPUT);
  digitalWrite(PIN_ESP8255_RST, LOW);
  delay(300);
  digitalWrite(PIN_ESP8255_RST, HIGH);
}

/*Reiniciar a placa Arduino*/
void software_Reset()
{
  asm volatile ("  jmp 0");
}

/*Sinalizar via LED a gravação do log de utilização de energía.
  @param flashTime informar o tempo em milissegundos para acender e apagar o LED.
*/
void saveLogBlink(long flashTime)
{
  digitalWrite(LED_LOG_SAVE, HIGH);
  delay(flashTime);
  digitalWrite(LED_LOG_SAVE, LOW);
}

/*Configuração do programa*/
void setup()
{
#ifdef DEBUG
  Serial.begin(74880); // A velocidde 74880 foi a mais estável na comunicação com o Módulo ESP8266.
#endif
  analogReference(INTERNAL); //Referência igual a 1,1 volts
  esp8266Reset(); //Reiniciar o módulo ESP8266 na primeira conexão para garantir que o módulo não esteja travado.
  esp8266.begin(74880);  // A velocidade 74880 foi a mais estável na comunicação com o Arduino.
  pinMode(SD_CS, OUTPUT); //The pin connected to the chip select line of the SD card, @link https://www.arduino.cc/en/Reference/SDbegin
  pinMode(LED_LOG_SAVE, OUTPUT); //Pin do LED que sinaliza a gravação do log de utilização de energia.
#ifdef DEBUG
  debug(F("Setup in five minuntes"));
#endif
  delay(5000);
  //Iniciar e verificar o funcionamento do cartão de memória:
  if (!SD.begin(SD_CS))
  {
#ifdef DEBUG
    debug(F("initialization failed!"));
#endif
    ohaStatus = OHA_STATUS_NOT_SD;
  } else {
    ohaStatus = OHA_STATUS_OK;
  }
}

/*Executar o fluxo do programa*/
void loop()
{
  //Se o cartão de memória estiver funcionando:
  if ( ohaStatus != OHA_STATUS_NOT_SD ) {
    //Verificar se a data e hora do sistema está atualizada.
    if ( currentDate.length() == 0 )
    {
      ohaStatus = OHA_STATUS_NOT_DATE;
      //Salvar log de utilização de energía se a data e hora do program estiver atualizada:
    } else {
      saveLogBlink(500);
      saveLog();
      saveLogBlink(400);
      saveLogBlink(400);
    }
  }
  //Verificar se existe requisições realizadas via o módulo ESP8266:
  if ( esp8266.available() )
  {
    espCheck = 0; //Zerar a contagem de verificação do ESP8266 quando for realizada qualquer requisição.
    doUrl(esp8266.readString()); //Executar a funcionalidade informada na URL.
    //Reiniciar o módulo ESP8266 após 10 execuções do fluxo se não for identificada nenhuma requisição via ESP8266.
  } else if ( espCheck > 10 ) {
    esp8266Reset();
  } else  {
    espCheck++; //Contar o número de verificações.
  }
  delay(3000); //Delay par amelhorar o tempo de fluxo para processar as requisições via ESP8266 e o tempo para gravar os registros de utilização de energia.
  if ( ohaStatus != OHA_STATUS_OK)
  {
#ifdef DEBUG
    debug(F("Status: "), ohaStatus);
#endif
  }
}

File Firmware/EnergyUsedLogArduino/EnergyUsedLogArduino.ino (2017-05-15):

/*
  EnergyUseLog - Ler e registrar o consumo de energia em amperes lendo os sensores SCT - 013 conectados ao circutio. 
                 Esse código e parte do projeto: https://github.com/brolam/OpenHomeAnalysis
  @author Breno Marques(https://github.com/brolam) em 12/12/2015.
  @version 1.00

  Este programa está dividido em blocos:
  B1 - Constantes
  B2 - Variáveis Globais
  B3 - Funcionalidades para ler, escrever e excluir arquivos no cartão de memoria.
  B4 - Funcionalidades para ler, registrar ou excluir os logs de consumo de energia no cartão de memoria.
  B5 - Funcionalidades para realizar a comunicação como o módulo WiFi.

  Ultima compilação:
   Opções de compilação alteradas, recompilando tudo
   O sketch usa 25020 bytes (77%) de espaço de armazenamento para programas. O máximo são 32256 bytes.
   Variáveis globais usam 1059 bytes (51%) de memória dinâmica, deixando 989 bytes para variáveis locais. O máximo são 2048 bytes.
*/

#include <SD.h>
#include <SoftwareSerial.h> //Necessária para a comunicação serial com o modulo WiFi ESP8266.

/****************************************************************************************************************************************************************
 Inicio do B1 - Constantes
 ****************************************************************************************************************************************************************/
//#define DEBUG 1 //Escrever no Monitor serial quando ativado, {@see debug()},
#define LED_LOG_SAVE 5                  //Informar a porta do LED, para sinalizar a gravação do log de consumo de energia. 

//Constantes utilizadas na geração dos logs.
#define AMOUNT_SCT 3                    //Quantidade de sensores SCT-013 suportado no circuito.  
#define LOGS F("LOGS")                  //Nome do diretório no cartão de memoria onde serão armazenados os logs de consumo de energia.
#define LOG_SEQ F("Seq")                //Nome do arquivo onde será armazenado o controle de sequência dos logs de consumo de energia.  
#define LOG_TIME_SAVE 10000             //Intervalo em Milissegundo para registrar o proximo log, {@see saveLog()}    

//Constantes utilizadas na gravação dos arquivos.
#define SD_CS 10                        //The pin connected to the chip select line of the SD card, @link https://www.arduino.cc/en/Reference/SDbegin
#define F_TMP F(".tmp")                 //Extensão para arquivos temporário, para mais detalhes {@see readResource()}  e {@see writeResource()}  
#define F_TXT F(".txt")                 //Extensão para arquivos definitivos, para mais detalhes {@see readResource()}  e {@see writeResource()}  
#define F_BEGIN F("<")                  //Sinalizar o inicio do arquivo, para mais detalhes {@see commitResource()} 
#define F_END F(">")                    //Sinalizar o final do arquivo, para mais detalhes {@see commitResource()} 

//Constantes utilizadas na comunicação com o modulo WiFi ESP8266
#define URL_LOG F("log")                //Solicitação de logs
#define URL_STATUS F("status")          //Solicitação(GET) ou alteração(POST) do Status do programa, para mais detalhes {@see setStatus()} e {@see sendStatus()} 
#define URL_RESET F("reset")            //Solicitação para reiniciar o Arduino, para mais detalhes {@see reset()}
#define LOG_DATE_NOT_EXISTS F("LOG_DATE_NOT_EXISTS") //Sinalizar que a data solicitado não existe.
#define LOG_FILE_NOT_EXISTS F("LOG_FILE_NOT_EXISTS") //Sinalizar que o log solicitado não existe.

//Constantes para definir o status de execução do programa.
#define OHA_STATUS_NOT_DATE F("OHA_STATUS_NOT_DATE")    //Sinalizar que a data do programa não está atualizada. 
#define OHA_STATUS_NOT_SD F("OHA_STATUS_NOT_SD")        //Sinalizar que o SD Card está com problema e os registros dos logs está parado.   
#define OHA_STATUS_OK F("OHA_STATUS_OK")                //Sinalizar que a data do programa está atualizada / registrando os logs de consumo de energia. 

/*Final do B1 - Constantes*/


/****************************************************************************************************************************************************************
 Inicio do B2 - Variáveis Globais
 ****************************************************************************************************************************************************************/
String ohaStatus = String("");                         //Armazenar o status atual do programa.
String currentDatePath = String("");                   //Armazenar a data atual para o registro dos logs no formato YYYYMMDD
String currentTime = String("");                       //Armazenar a hora + minutos atual para o registro dos logs no forma HHmm
String currentDelDate = String("");                    //Armazenar a data para excluir os logs para liberar o espaço no cartão de memória.
int currentSeq = 1;                                    //Armazenar a sequência atual de geração dos logs.
unsigned long millisOnSetTime = 0;                     //Armazenar o total de Milissegundo {@see millis()}, quando a data e hora do programa foi atualizada, para mais detalhes veja {@see setDate()}
unsigned long timeSaveLog = 0;                         //Armazenar o tempo que o ultimo log foi salvo, por favor, veja {@see saveLog()} para mais detalhes.
byte espCheck = 0;                                     //Armazenar o total de verificação do status do modulo ESP8266 {@see esp8266Reset()}.

SoftwareSerial esp8266(2, 3); //Comunicação serial com o modulo ESP8266.

#ifdef DEBUG
void debug(String title, String value) {
  Serial.print(title); Serial.println(value);
}
#endif

#ifdef DEBUG
void debug(String title) {
  Serial.println(title);
}
#endif

/*Reiniciar a placa Arduino*/
void software_Reset()
{
  asm volatile ("  jmp 0");
}


/*Final do B2 - Variáveis Globais*/


/***************************************************************************************************************************************************************
 Inicio do B3 - Funcionalidades para ler, escrever e excluir arquivos no cartão de memória.
 Visão geral: Neste bloco é centralizada todas as funcionalidades base para leitura e escrita de arquivos no cartão de memória, também é importante destacar 
              o controle simples de confirmação de escrita com sucesso realizado nos metodos {@see getResource()} e {@see setResource()} para que valores 
              inconsistentes sejam desconsiderados.
 ***************************************************************************************************************************************************************/
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

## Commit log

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2017-01-30 [Firmware] EnergyUsedLogEsp8266 - Adicionado o Config_model.h copiar o Config_model.h para Config.h para definir as configurações locais que serão ignoradas no controle de versão.
2017-01-30 [Firmware] EnergyUsedLogEsp8266 - Remover Config.h com as configuraçõe locais do controle de versão.
2017-02-01 [Firmware] [Android] Integração das situações retornada na API entre o Arduino e o App Android.
2017-03-17 fix: Definir o nome do ESP8266 na rede.
    O método WiFi.hostname não estava sendo chamado no setup do Firmware.
    [EnergyUsedLogEsp8266.ino]
2017-03-17 feat: Disponibilizar funcionalidades para converter e formatar texto, número, data e etc.
2017-03-20 feat: Teste unitário da OhaEnergyUseApi.setStatus
    Realizar teste do método da OhaEnergyUseApi.setStatus conectado ao Registrador de Logs de Consumo de Energia.
2017-03-21 feat: Teste unitário da OhaEnergyUseApi.getConnection
    Realizar teste do método da OhaEnergyUseApi.getConnection conectado ao Registrador de Logs de Consumo de Energia.
2017-03-22 feat: Teste unitário da OhaEnergyUseApi.getStatus
    Realizar teste do método da OhaEnergyUseApi.getStatus conectado ao Registrador de Logs de Consumo de Energia.
2017-03-23 feat: Teste unitário da OhaEnergyUseApi.getLogs
    Realizar teste do método da OhaEnergyUseApi.getLogs conectado ao Registrador de Logs de Consumo de Energia.
2017-03-23 fix: Correção dos métodos getConnection e reset.
    getConnection: Não enviar essa requisição também para o Arduino, porque o processamento desse método é realizado no ESP8266.
    reset: enviar para o solicitante (client) o flag de final de requisição OHA_REQUEST_END.
    [EnergyUsedLogEsp8266.ino]
2017-03-23 feat: Teste unitário da OhaEnergyUseApi.reset e OhaEnergyUseApiV1Test.ohaEnergyUseApiAllMethods
    Realizar teste do método da OhaEnergyUseApi.reset e todos os métodos conectado ao Registrador de Logs de Consumo de Energia.
2017-03-24 fix: Renomear o app para appSupervisory
    Renomear o aplicativo para melhorar a identificação.
2017-03-24 feat: OhaEnergyUseContract
    Organizar o acesso e gravação nas tabelas e colunas do banco de dados onde será registrado a utilização de energia.
2017-03-25 feat: OhaEnergyUseProvider - Inclusão de logs de utilização de energia.
    Disponibilizar informações da utilização de energia através de um ContentProvider, adicionada a inclusão de logs de utilização de energia.
2017-03-26 feat: OhaSQLHelper
    Gerencia um banco de dados local para dados do supervisory.
2017-03-28 feat: OhaStatusLog - novo método exists
    Verificar se existe um OhaStatusLog em uma lista de textos.
2017-03-29 feat: OhaStatusLog novo status OHA_REQUEST_TIMEOUT.
    Sinalizar que o Arduino não está respondendo ao módulo WIFI ( ESP8266)
2017-03-30 fix: OhaEnergyUseLog - Remover a tradução de mensagens.
    Remover a tradução dessa classe, somente lançar a exceção para a UI realizar a tradução.
2017-03-31 feat: OhaHelper - Novos métodos getAmountDays, getDateBegin e getDateEnd.
    getAmountDays - Recuperar a quantidade de dias entre duas datas;
    getDateBegin - Recuperar uma data reiniciando a hora;
    getDateEnd - Recuperar uma data com a hora final do dia.
2017-03-31 fix: Executar o reset sem verificar o status.
    O reset via ESP8266 deve ser executado sem verificar o status.
    [EnergyUsedLogArduino.ino]
2017-04-01 fix: Correções nos métodos sendLog e setStatus.
    sendLog - Verificar se a comunicação serial está disponível antes de enviar o log.
    setStatus - Por segurança, localizar(searchLastSequence) a última sequencia do log se não for possível recuperar
    a sequência atual no arquivo de recursos(Seq.txt).
    [EnergyUsedLogArduino.ino]
2017-04-02 feat: OhaHelper - Novas funcionalidades formatNumber, formatAccuracyDay, convertMillisToHours e convertWattsToKWH.
    formatNumber - Recuperar uma número formatado conforme o decimalFormat;
    formatAccuracyDay - Recuperar o percentual da precisão de um tempo sobre 24 horas;
    convertMillisToHours - Converter milisegundos em horas;
    convertWattsToKWH - Converter o total de Watts em Kwh.
2017-04-02 fix: EnergyUsedLogArduino sendLog - evitar loops infinitos.
    Foi incluido um limite de 10 tentativas na verificação de overflow entre a comunicação com módulo WiFI para evitar loops infinitos.
    [EnergyUsedLogArduino.ino]
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2017-04-06 fix: OhaEnergyUseDaysCursor - Correção da soma de KWH por dia.
    Substituir a consulta por faixa de datas por um GROUP BY, mas essa solução não é definitiva.
    Será desenvolvido uma solução para facilitar a soma por Dia, Semana, Mês e etc.
    [OhaEnergyUseProvider.java]
2017-04-07 feat: Adicionado os arquivos de manifest, gradle e dependências dos projetos Android.
2017-04-07 feat: Caso de teste - Consumo de Energia no Dia:
    - Incluir uma simulação da utilização 24KWH no dia 01/01/2015.
    - Realizar um consulta e testar os seguintes resultados:
    - Data Inicio : 01/01/2015
    - Duração: 24Hs
    - KWH : 24.00
2017-04-07 feat: OhaStatusLog - recuperar a duração de execução em milissegundos da placa Arduino desde o último reset.
    Adicionando esse campo na class OhaStatusLog, será possível remover a class br.com.brolam.oha.supervisory.apiV1.models.OhaSequenceLog do projeto.
2017-04-07 fix: EnergyUsedLogArduino - não recupear a última sequencia de log no método sendStatus.
    A última sequencia não será mais utilizada para identificar fim da geração de logs,
    será utilizado os status OHA_STATUS_FINISHED + LOG_FILE_NOT_EXISTS
    [EnergyUsedLogArduino.ino]
2017-04-08 fix: OhaEnergyUseContract - salvar a duração em segundos e não em milisegundos.
    Salvar a duração em segundos para utilizar a mesma unidade de medida dos campos watts, já que um 1 Wh =3600 J ou ((W X Segundos) / 3600).
2017-04-09 feat: Sincronização dos Logs de Utilização de Energia.
    OhaEnergyUseSyncService - Executar em background a OhaEnergyUseLogTask.
    OhaEnergyUseLogTask - Realizar a importação dos logs de utilização de energia e monitorar o funcionamento
    do Registrador de Utilização de Energia.
2017-04-11 fix: OhaEnergyUseContract - alteração de COLUMNS_SUM_WATTS para COLUMNS_CALC.
    [OhaEnergyUseProvider.java]
2017-04-14 feat: OhaEnergyUseContract - Nova tabela EnergyUseBill e melhorias no acesso a tabela energyUserLog.
    EnergyUseBill - registar o período e valor da conta de energia.
    EnergyUserLog - otimização do indice INDEX_DATE_TIME e campos para consultar o utilização diária de energia.
2017-04-18 feat: Layouts para exibir os detalhes da utilização de energia.
    layout-w480dp/holder_energy_use_watts.xml - Exibir uma linha com os valores da utilização de energia por Watts em telas maiores que 480dp.
    layout/holder_energy_use_watts.xml - Exibir uma linha com os valores da utilização de energia por Watts em telas menores que 480dp.
    layout-w480dp/holder_energy_use_wh.xml - Exibir uma linha com os valores da utilização de energia por Watts Horas ee telas maiores que 480dp.
    layout/holder_energy_use_wh.xml - Exibir uma linha com os valores da utilização de energia por Watts Horas em telas menores que 480dp.
    layout-w480dp/title_energy_use_wh.xml - Exibir uma linha com os títul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
2017-04-19 feat: Adicionado o cursor para consultar os cartões de conta de energir e melhorias no cursor de utilização de energia por dia.
2017-04-20 fix: OhaEnergyUseContract - correção do nome do parametro PATH_DAYS_PARAM_BEGIN_DATE para PATH_DAYS_PARAM_END_DATE e correção do SQL para criar o index idx_energyUserLog_date_time.
2017-04-23 feat: Disponibilizar o cursor para consultar os cartões de conta de energia.
2017-04-24 feat: adicionado as funcionalidades básicas para realizar o backup e restore do banco de dados.
2017-04-24 fix: OhaEnergyUseProvider - adicionado a notificação de atualização para o URI OhaEnergyUseContract.CONTENT_URI_BILL.
    [OhaEnergyUseProvider.java]
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2017-04-26 feat: Adicionado a primeira versão das telas principal e detalhes de utilização de energia.
    [app_bar_main.xml]
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2017-04-29 fix: OhaEnergyUseLogTask - A data e hora de importação não pode ser maior do que a data e hora atual:
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2017-05-02 fix: OhaSettingsActivity - Informar o tempo de funcionamento do registrador de utilização de energia.
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2017-05-03 fix: OhaEnergyUseLogTask - Correção da duração padrão de leitura de um log de utilização de energia.
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2017-05-11 fix: OhaEnergyUseBillFragment - atualizar o custo do Kwh com o valor do EditText antes de salvar a conta de energia.
2017-05-11 fix: Remover atalhos de funcionalidades que não estão desenvolvidas.
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2017-05-14 fix: OhaHelper.formatAccuracy - Correção do percentual de precisão do tempo total de leitura.
2017-05-14 fix: Correções de layout para Tablets.
2017-05-15 fix: considerar o símbolo monetário padrão para o usuário.
2017-05-15 fix: EnergyUsedLogArduino - Remover a funcionalidade searchLastSequence para reduzir o tamanho do programa.
    [EnergyUsedLogArduino.ino]
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2017-05-17 fix: OhaEnergyUseLogTask - Aumentar o tempo do delay para melhorar a Accuracy.
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2017-05-17 docs: Adicionado imagens e projeto no Fritzing
    [OhaEnergyUseLog.fzz]
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2017-05-18 fix: OhaEnergyUseDaysCursor - NullPointerException quando não existe uma conta de energia para o dia analisado.
2017-05-18 fix: OhaMainActivity Incluir nova Conta de Energia - Reiniciar o cursor para exibir a nova conta:
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2017-05-18 fix: OhaRestoreDatabaseFragment - NullPointerException quando a lista de backups está vazia.
2017-05-19 fix: OhaDatePickerDialogPreference - correções para minSdkVersion < 23.
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2017-05-19 fix: OhaEnergyUseProviderTest - Atualização do procedimento de teste.
2017-05-20 fix: OhaSettingsActivity - Exibir os valores padrão na primeiro acesso a tela de configurações.
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2017-06-05 fix: - Modificações para aumentar o tempo total de registros da utilização de energia e reduzir as operações leitura do Micro SD. issue #7
    [EnergyUseLoggerArduino.ino]
2017-06-08 feat: app Supervisory - Preferências / Quantidade de dias de armazenamento no Micro SD Card.
    Permitir ao usuário definir na funcionalidade de preferências a quantidade de dias com registros de utilização de energia, que devem ser mantidos no Micro SD Card do registrador de utilização de energia. Objetivo: Utilizar toda a capacidade de armazenamento e também aumentar a vida útil do Micro SD Card. Issue #7
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2018-09-28 fix: sendLogs do not send LOG_END_OF_FILE #13
    [EnergyUseLoggerArduino.ino, OhaEnergyUseProvider.java]
2019-03-06 fix: automatic reset EnergyUseLogger
    [EnergyUseLoggerArduino.ino]
